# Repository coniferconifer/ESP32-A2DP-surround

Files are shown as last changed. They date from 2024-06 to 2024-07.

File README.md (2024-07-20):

# Surround Sound Experiment Using Speaker Matrix Method by ESP32-A2DP

In the 1970s, various methods were developed to attempt 5.1-channel surround sound conversion from 2-channel audio sources using the speaker matrix method. During that time, engineers devised creative wiring solutions to provide R-L signals to the right rear speaker and L-R signals to the left rear speaker. However, with today's power amplifiers utilizing Balanced Transformer Less (BTL) outputs, connecting speakers in a matrix configuration can be risky.

Personally, I use a 2.1-channel PC speaker system, where the ".1" refers to the dedicated subwoofer for low-frequency sounds. While I'm satisfied with this setup, I've always been curious about experiencing surround sound using the speaker matrix approach.

# Surround processor by OP-amp

To explore this, I built an OP-amp circuit capable of generating R-L and L-R signals similar to the speaker matrix method for rear speakers.
I connected this circuit to a rear speaker power amplifier (such as PAM8403 or ST893) and tried the resulting surround effect. 

Ref.surroundAMP.png surroundAMP.kicad_sch for Kicad schematic editor.

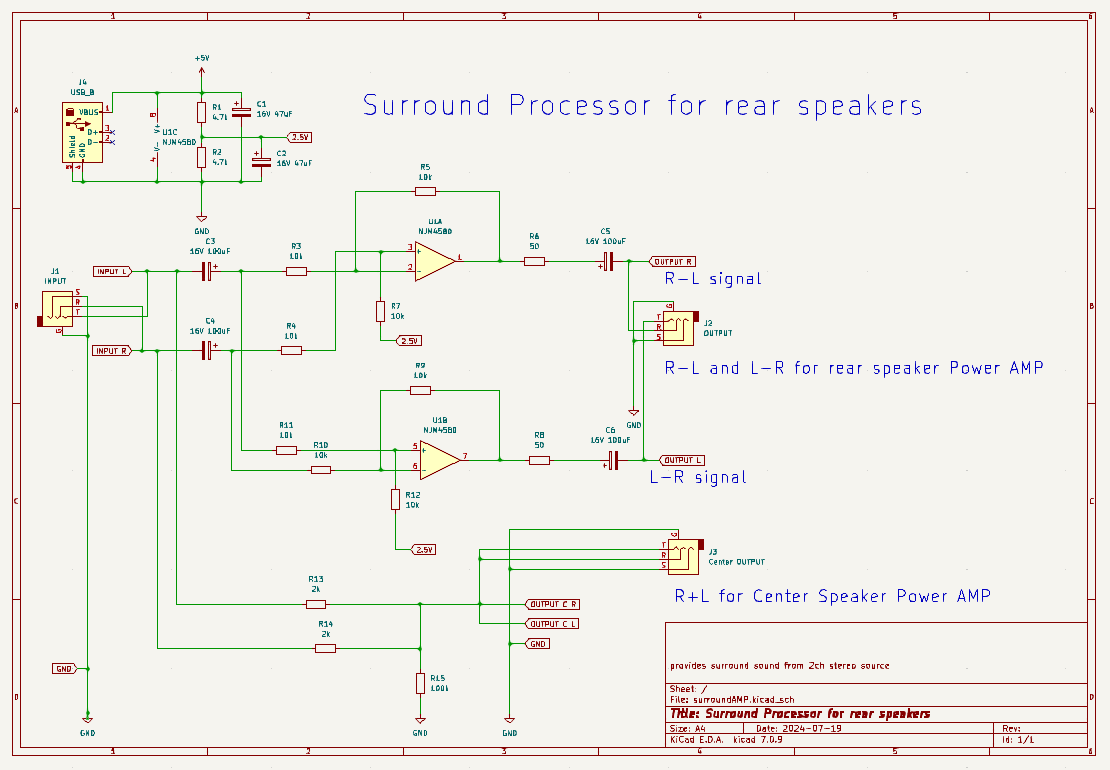
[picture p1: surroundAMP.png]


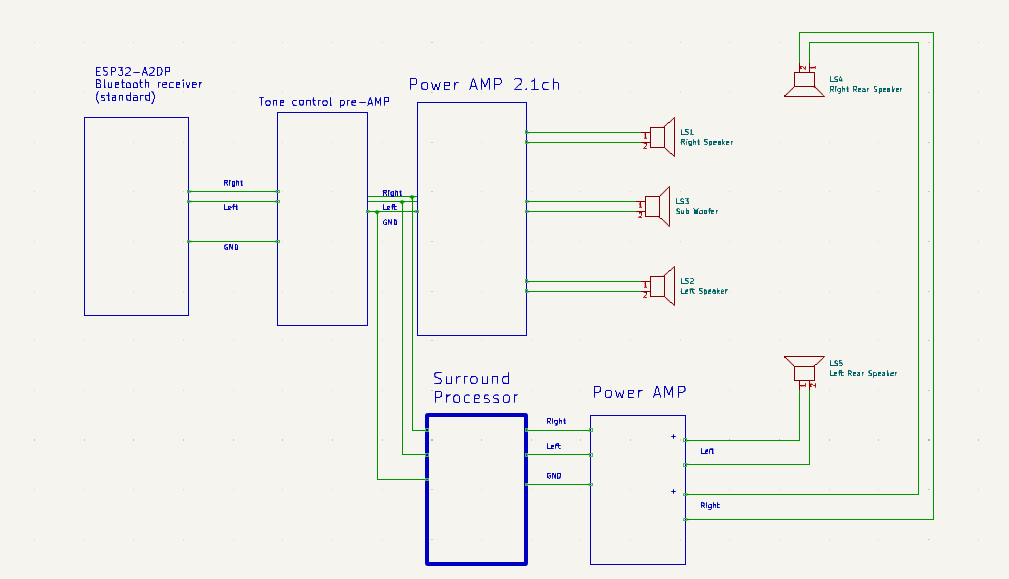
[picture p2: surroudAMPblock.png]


Indeed, the differential R-L signals allow playback of sounds originating from areas other than the stereo microphone's center, creating a wider soundstage during live playback or applause in 2-channel audio sources.

# MX-15 emulation by ESP32-A2DP

The famous designer Nagaoka Tetsuo implemented a matrix speaker system where the left speaker carried 2L-R signals, the center speaker played R+L, and the right speaker played 2R-L signals. I wonder what kind of audio experience this configuration would yield.

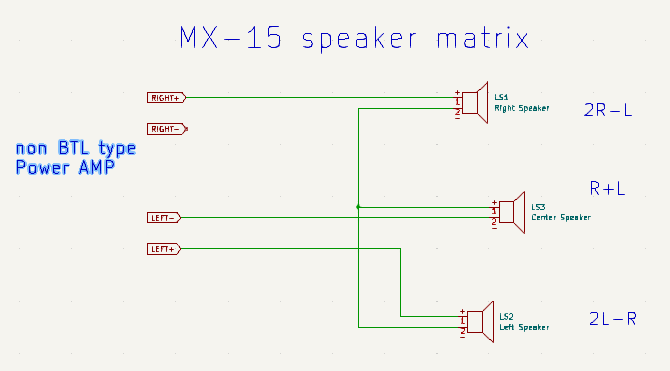
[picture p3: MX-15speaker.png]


To achieve this, I used the ESP32-A2DP library to receive Bluetooth audio and extract 2-channel stereo PCM data within callback functions. I then processed this data to create separate 2L-R and 2R-L signals for the left and right speakers. For the R+L signal intended for the center speaker, I used a simple analog mixer with two 2k-ohm resistors and a 100k-ohm resistor. The DAC (PCM5201A) was wired according to the standard GPIO usage of the ESP32-A2DP library.

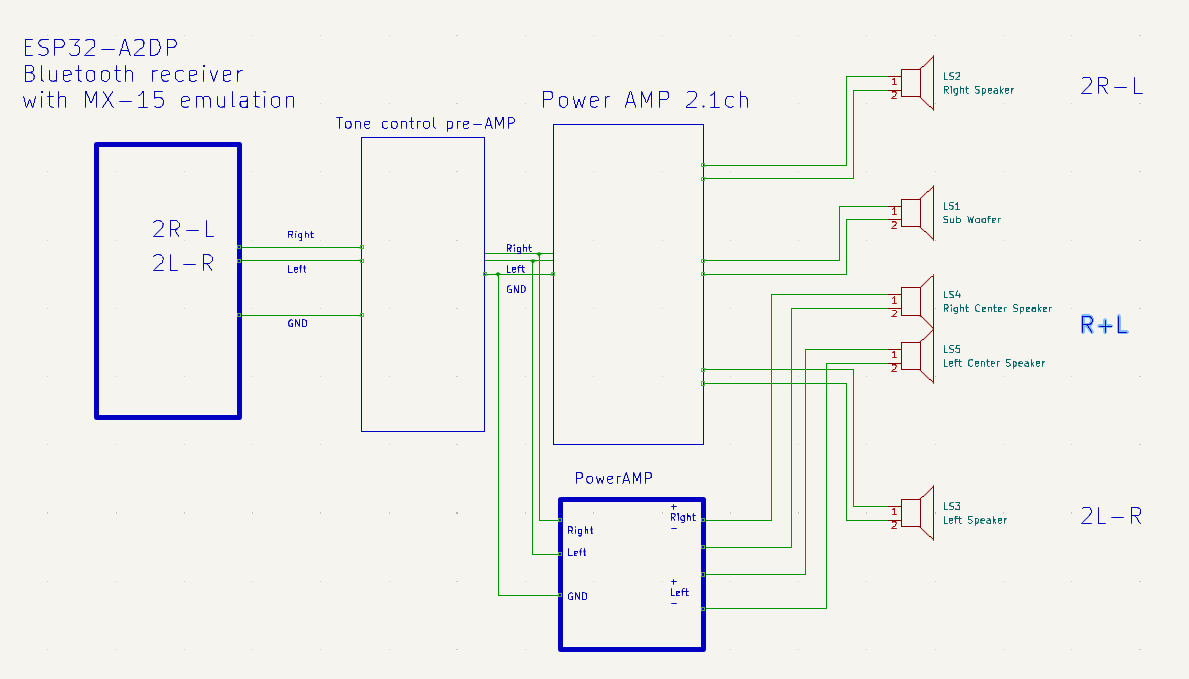
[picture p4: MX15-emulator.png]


Keep in mind that a power amplifier is necessary to drive the speakers from the DAC output. Existing PC speakers are used to play 2L-R and 2R-L.  
For the center speaker, I used a small, inexpensive speaker with a built-in power amplifier. 
The result was a surround sensation, although not precisely 2.1-channel due to the unique configuration.

If you prefer to use Rear speakers,  L-R, R-L OP-amp surround processor is included , 2L-R and 2R-L are processed as 
<pre> 
Left channel (2L-R)-(2R-L) => 3*(L-R) 
Right channel (2R-L)-(2L-R) => 3*(R-L) 
</pre>
and surround processor by OP-amp works as well.

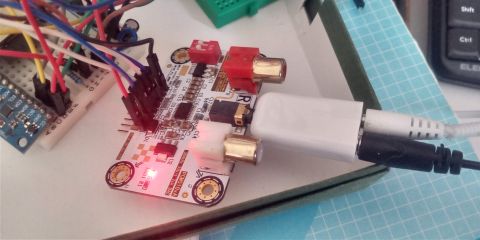
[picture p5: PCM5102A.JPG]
 DAC PCM5102A output has a splitter for 2.1ch PC speaker and small center speakers.

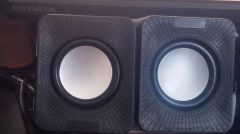
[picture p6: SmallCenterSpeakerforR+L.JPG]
 small powered speakers for center (mixed 2L-R and 2R-L are equivalent to R+L )

Referemces:

[1] https://www.pschatzmann.ch/home/2023/07/08/esp32-mixing-a2dp-with-a-sine-signal/

[2] https://github.com/pschatzmann/ESP32-A2DP

[3] MX-15 speaker by Tetsuo Nagaoka

In Japanese

# ESP32-A2DPによるスピーカマトリクス方式の音声受信

スピーカマトリクス法による2ch音源を5.1chサラウンド化する試みは1970年台にさまざまな方法が開発されていたそうです。
右側のリアスピーカにR-L信号,左のリアスピーカにL-R信号を与えるには、当時はスピーカーの配線を工夫することで実現されていましたが、
現在のパワーアンプはBTL(Balanced Transformer Less)出力のため、左右のスピーカのマイナス側は共通のGNDではないためスピーカーをマトリクスつなぎにするのは危険です。

現在2.1chのPCスピーカを愛用しています。.1は低音専用のサブウーファのことです。
これで十分満足していますが、スピーカマトリクスのサラウンドも体験してみたい。

# オペアンプでサラウンド回路を作る。
そこで、スピーカマトリクス法と同じR-L,L-R信号を生成するOPアンプの回路を作ってリアスピーカ用のパワーアンプ(PAM8403やST893)につないでみたところサラウンド感を知ることができました。
(回路図をsurroundAMP.png Kicad用データはsurroundAMP.kicad_schとして掲載）

聞いてみると確かにR-Lのような差分は、ステレオマイクの中央部以外からくる音を再生できています。
R-LとL-Rは逆相になるので音源の所在感はなく、2ch音源のライブを再生するとリアから拍手が広がって聞こえます。

これは面白いですね。

# MX-15 をESP32-A2DPで実現してみる。

有名な長岡鉄男氏の設計したマトリックススピーカでは　左に2L-R 中央にR＋L　右に2R-L 信号が出せるようにスピーカーをつないでいました。どんな音が得られるのでしょうか。

そこで、ESP32-A2DPライブラリを活用して、Bluetoothで受信しコールバック関数の中で抽出できる2chステレオPCMデータを加工して左用2L-R,右用2R-Lを作ってみました。
センタースピーカ用のR＋L信号は2kオームの抵抗2本と100kオームで作るアナログミキサで生成できます。
ミキサ回路がない場合は、小さいスピーカーなら左右を寄せてしまえば空間的にR+Lになります。（2L-R + 2R-L => L＋R になるからです。)

DACにはPCM5102Aを接続しており、配線はESP32-A2DPライブラリの標準的なGPIOの使い方に合わせてあります。

DACの出力からスピーカを鳴らすにはパワーアンプは必要です。
センタースピーカーはパワーアンプ入りの小さなスピーカを使いました。
結果としては2.1ch+センタースピーカでは2.1chではなかったサラウンド感はありました。

リアスピーカも併せて使うと、すでにOP-ampによるサラウンド効果が入っていますので、
<pre> 
Left channel (2L-R)-(2R-L) => 3*(L-R) 
Right channel (2R-L)-(2L-R) => 3*(R-L) 
</pre>
となってリアスピーカからはサラウンド効果のある差分が強化されて出てきます。
お好みでリア用のパワーアンプのボリュームを変えてください。

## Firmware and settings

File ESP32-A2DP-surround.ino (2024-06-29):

// based on https://www.pschatzmann.ch/home/2023/07/08/esp32-mixing-a2dp-with-a-sine-signal//
// and ESP32 A2DP Arduino library at https://github.com/pschatzmann/ESP32-A2DP
// converted into surround speaker emulator mimicing MX-15 speaker matrix by Tetsuo Nagaoka
// 
// This program works as ESP-32 A2DP receiver and converts R,L signals into 2R-L and 2L-R.
// 
// R+L for center speaker needs to be made from resister mixer as follows.
// R(2R-L) and L(2L-R) channel come from DAC (PCM5102A) output.
//
// 2kOhm x 2 , 100kOhm for GND
// R-----2kOhm -------+-------Rch Output
//                    |
//                    +--100kOhm-----GND Input/Output
//                    |
// L-----2kOhm -------+-------Lch Output
// for small powered speakers placed side by side or stacked ,
// it may be OK without hardware mixer. 
// Because sound from 2R-L + sound from 2L-R => R+L at hearing position.
//
/* PCM5102A board is connected by
GPIO22 -> DIN
GPIO15 -> LCK
GPIO14 -> BCK
5V -> VIN (inout to the on board 3.3V regulator)
GND -> GND
default pin by https://github.com/pschatzmann/ESP32-A2DP

On board switch settings: H1L（FLT),H2L（DEMP),H4L（FMT) are shorted to GND
H3L（XMST un mute ) is connected to High side(3.3V)

copyright 2024 by coniferconifer
LICENSED under apache

To avoid followin message, 

>Sketch uses 1889957 bytes (144%) of program storage space. Maximum is 1310720 bytes.
>Global variables use 62276 bytes (19%) of dynamic memory, leaving 265404 bytes for local variables. Maximum is 327680 bytes.
>Sketch too big; see https://support.arduino.cc/hc/en-us/articles/360013825179 for tips on reducing it.
>text section exceeds available space in board
>
>Compilation error: text section exceeds available space in board

select partition scheme "NO OTA" from Arduino IDE's tools menu

*/

#include "AudioTools.h"        // https://github.com/pschatzmann/arduino-audio-tools
#include "BluetoothA2DPSink.h" // https://github.com/pschatzmann/ESP32-A2DP

AudioInfo info(44100, 2, 16);
BluetoothA2DPSink a2dp_sink;
I2SStream i2s;
OutputMixer<int16_t> mixer(i2s, 2);

const int buffer_size = 16 * 20;  // split up the output into small slices
uint8_t surround_buffer[buffer_size];

uint8_t mode = 2;  // 0.. passthrough , 1..speaker matrix , 2..MX-15 mode speaker matrix
#define PASSTHROUGH 0
#define SPEAKERMATRIX 1
#define MX15MODE 2
void setup() {
  mode = MX15MODE;

  Serial.begin(115200);
  AudioLogger::instance().begin(Serial, AudioLogger::Warning);
  Serial.printf("ESP32 A2DP surround processor by speaker matrix emulation\r\n");
  switch (mode){
    case PASSTHROUGH:
      Serial.printf("pass through mode\r\n");
      break;
    case SPEAKERMATRIX:
      Serial.printf("L-R,R-L Speaker Matrix mode\r\n");
      break;
    case MX15MODE:
      Serial.printf("MX-15 (2L-R,2R-L) mode\r\n");
      break;
    default:
      break;
  }
  // setup Output mixer with min necessary memory
  mixer.begin(buffer_size);
  // Register data callback
  a2dp_sink.set_stream_reader(read_data_stream, false);

  // Start Bluetooth Audio Receiver
  a2dp_sink.set_auto_reconnect(false);
  a2dp_sink.start("a2dp-i2s");

  // Update sample rate
  info.sample_rate = a2dp_sink.sample_rate();

  // setup output
  auto cfg = i2s.defaultConfig();
  cfg.copyFrom(info);
  // cfg.pin_data = 23; // https://github.com/pschatzmann/ESP32-A2DP/wiki/A2DP-Sink-Optimizations
    //cfg.pin_bck = 14;
    //cfg.pin_ws = 15;
    //cfg.pin_data = 22;
  cfg.buffer_count = 8;
  cfg.buffer_size = 256;
  i2s.begin(cfg);
}

void loop() {
  delay(100);
}

void read_data_stream(const uint8_t *data, uint32_t length) {
  // To keep the mixing buffer small, we split up the output into small slices
  const int sliceSize = buffer_size;
  int16_t RchData, LchData;
  //Serial.printf("length=%d\r\n", length);
  for (int j = 0; j < length; j += sliceSize) {
    // Write j'th a2dp slice
    int remaining = min(sliceSize, static_cast<int>(length - j));
    //   Serial.printf("remaining=%d j=%d\r\n",remaining,j);

    for (int i = j; i < (j + remaining); i = i + 4) {
      int16_t leftData = (int16_t)(data[i] | (data[i + 1] << 8));
      int16_t rightData = (int16_t)(data[i + 2] | (data[i + 3] << 8));
      //#define PASSTHROUGH
      switch (mode) {
        case PASSTHROUGH:
          LchData = leftData;
          RchData = rightData;
          break;
        case SPEAKERMATRIX:  // output surround soun for rear speaker : R-L, L-R
          LchData = leftData - rightData;
          RchData = rightData - leftData;
          break;
        default:  //MX15MODE
          // Tetsuo Nagaoka's MX-15 matrix speaker mode by default
          LchData = (leftData - rightData / 2) ;
          RchData = (rightData - leftData / 2) ;
          // you can get R+C for center speaker by analog resister mixer from Rch and Lch
          // (L/2-R/4) + (R/2-L/4) => (R+L)/4
          // two 2kOhm and one 100kOhm are enough for mixer
          break;
      }
      surround_buffer[i - j] = (uint8_t)(LchData & 0xff);
      surround_buffer[i - j + 1] = (uint8_t)(LchData >> 8);
      surround_buffer[i - j + 2] = (uint8_t)(RchData & 0xff);
      surround_buffer[i - j + 3] = (uint8_t)(RchData >> 8);

      // Serial.printf("%d %d  i/4-j/4 %d\r\n", leftData,rightData,i/4-j/4);
    }

    mixer.write(surround_buffer, remaining);
    mixer.write(surround_buffer, remaining);
  }
}

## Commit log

2024-06-26 surround processor
    makes 2L-R , 2R-L from L and R signal received by ESP32 A2DP
2024-06-26 FYI hardware OP amp circuit to make R-L, L-R , R+L signal from R and L signal for surround sound
    [surroundAMP.kicad_sch]
2024-07-08 comments added
    [surroundAMP.kicad_sch]
2024-07-18 resister 4.7k for 2.5V Power supply are specified
    [surroundAMP.kicad_sch]
2024-07-19 audio jack added
    [surroundAMP.kicad_sch]
2024-07-20 MX-15 speaker matrix schematic
2024-07-20 USB microB connector is added
    [surroundAMP.kicad_sch]
